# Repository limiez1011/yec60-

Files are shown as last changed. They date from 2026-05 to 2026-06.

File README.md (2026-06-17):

# yec60%

## Description
The yec60% keyboard is based on the ansi 60% layout and has 61 hotswappable sockets.

## Features
- Built in rp2040 MCU
- QMK firmware
- Hot swap sockets

## Flashing procedure
To flash firmware onto the RP2040 there are 2 pads under the "BOOT" text on the silkscreen, you must short those 2 pins to enter bootloader. Once in bootloader a drive should appear on your computer. Copy the .uf2 file from the QMK folder of the repo and paste it into the drive. Once done unplug the USB cable and plug it back in and it should be flashed.

## Credits
Credits to aio3 for his amazing tools for keyboard design, and his premade footprints. Some other people I'd love to thank is the QMK team which have created an amazing and easy to use system.

## BOM
|Name |Purpose |Quantity|Total Cost (USD)|Link |Distributor|
|---|---|---|---|---|---|
|stabilizers  |stabilizing |1 |11.00 |https://www.aliexpress.com/item/1005004229140548.html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 |aliexpress |
|keycaps |keycaps |1 |16.50 |https://www.aliexpress.com/item/1005009426980407.html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|aliexpress |
|switches |gateron milky yellow|70 |26.50 |https://www.aliexpress.com/item/1005007039372956.html?spm=a2g0o.cart.0.0.bc85452cwC4OF7&mp=1 |aliexpress |
|PCB |pcb |5 |30.00 | |JLCPCB |
|kalih sockets|hotswap |61 |3.00 |https://www.lcsc.com/product-detail/C41430893.html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 |LCSC |
|2mb flash |storage |1 |1.50 |https://www.lcsc.com/product-detail/C2986331.html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 |LCSC |
|PASSIVES |PASSIVING |1 |8.50 | |LCSC |
|DIODES |NKEY ROLLOVER |61 |4.00 |https://www.lcsc.com/product-detail/C81598.html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 |LCSC |
|XTAL |CLOCK |1 |1.00 |https://www.lcsc.com/product-detail/C9002.html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 |LCSC |
|USBC |PORT |1 |1.00 |https://www.lcsc.com/product-detail/C165948.html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 |LCSC |
|RP2040 |MCU |1 |1.00 |https://www.lcsc.com/product-detail/C2040.html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 |LCSC |
|RT9013-33GB  |LDO |1 |1.00 |https://www.lcsc.com/product-detail/C47773.html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 |LCSC |

## Photos









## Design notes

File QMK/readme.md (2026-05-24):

# yec60

yec60

*A short description of the keyboard/project*

* Keyboard Maintainer: [limiez1011](https://github.com/limiez1011)
* Hardware Supported: *The PCBs, controllers supported*
* Hardware Availability: *Links to where you can find this hardware*

Make example for this keyboard (after setting up your build environment):

    make yec60:default

Flashing example for this keyboard:

    make yec60:default:flash

See the [build environment setup](https://docs.qmk.fm/#/getting_started_build_tools) and the [make instructions](https://docs.qmk.fm/#/getting_started_make_guide) for more information. Brand new to QMK? Start with our [Complete Newbs Guide](https://docs.qmk.fm/#/newbs).

## Bootloader

Enter the bootloader in 3 ways:

* **Bootmagic reset**: Hold down the key at (0,0) in the matrix (usually the top left key or Escape) and plug in the keyboard
* **Physical reset button**: Briefly press the button on the back of the PCB - some may have pads you must short instead
* **Keycode in layout**: Press the key mapped to `QK_BOOT` if it is available

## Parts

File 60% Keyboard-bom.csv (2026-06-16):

Name | Purpose | Quantity | Total Cost (USD) | Link | Distributor
stabilizers | stabilizing | 1 | 11.00 | https://www.aliexpress.com/item/1005004229140548.html | aliexpress
keycaps | keycaps | 1 | 16.50 | https://www.aliexpress.com/item/1005009426980407.html?scm_id=1007.40050.354490.0&scm-url=1007.40050.354490.0 | aliexpress
switches | cherry mx red (62 bc one spare) | 70 | 26.50 | https://www.aliexpress.com/item/1005007039372956.html?spm=a2g0o.cart.0.0.bc85452cwC4OF7&mp=1 | aliexpress
PCB | pcb | 5 | 30.00 |  | JLCPCB
kalih sockets | hotswap | 61 | 3.00 | https://www.lcsc.com/product-detail/C41430893.html | LCSC
2mb flash | storage | 1 | 1.50 | https://www.lcsc.com/product-detail/C2986331.html | LCSC
PASSIVES | PASSIVING | 1 | 8.50 |  | LCSC
DIODES | NKEY ROLLOVER | 61 | 4.00 | https://www.lcsc.com/product-detail/C81598.html | LCSC
XTAL | CLOCK | 1 | 1.00 | https://www.lcsc.com/product-detail/C9002.html | LCSC
USBC | PORT | 1 | 1.00 | https://www.lcsc.com/product-detail/C165948.html | LCSC
RP2040 | MCU | 1 | 1.00 | https://www.lcsc.com/product-detail/C2040.html | LCSC
RT9013-33GB | LDO | 1 | 1.00 | https://www.lcsc.com/product-detail/C47773.html | LCSC

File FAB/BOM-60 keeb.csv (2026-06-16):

Comment | Designator | Footprint | LCSC | Quantity
100nF | C10,C11,C13,C14,C17,C19,C4,C5,C6,C7,C8,C9 | C_0402_1005Metric | C1525 | 12
10K | R5,R7 | R_0402_1005Metric | C25744 | 2
1K | R6 | R_0402_1005Metric | C11702 | 1
1uF | C1,C2 | C_0603_1608Metric | C15849 | 2
1uF | C12,C3 | C_0402_1005Metric | C52923 | 2
27 | R1,R2 | R_0402_1005Metric | C25156 | 2
33pF | C15,C16 | C_0402_1005Metric | C1562 | 2
5.1K | R3,R4 | R_0402_1005Metric | C25905 | 2
RP2040 | U1 | QFN-56-1EP_7x7mm_P0.4mm_EP3.2x3.2mm | C2040 | 1
RT9013-33GB | U2 | SOT-23-5_HandSoldering | C47773 | 1
USB_C_Receptacle_USB2.0_14P | J1 | USB_C_Receptacle_HRO_TYPE-C-31-M-12 | C165948 | 1
W25Q128JVSIQ | U3 | Winbond_USON-8-1EP_3x2mm_P0.5mm_EP0.2x1.6mm | C2986331 | 1
X322512MSB4SI | X1 | CRYSTAL-SMD_4P-L3.2-W2.5-BL | C9002 | 1
~ | SW10,SW11,SW12,SW13,SW14,SW15,SW16,SW17,SW18,SW19,SW2,SW20,SW21,SW22,SW23,SW24,SW25,SW26,SW27,SW28,SW29,SW3,SW30,SW31,SW32,SW33,SW34,SW35,SW36,SW37,SW38,SW39,SW4,SW40,SW41,SW42,SW43,SW44,SW45,SW46,SW47,SW48,SW49,SW5,SW50,SW51,SW52,SW53,SW54,SW55,SW56,SW57,SW58,SW59,SW6,SW60,SW61,SW62,SW7,SW8,SW9 | MXOnly-1U-Hotswap | C41430893 | 61
~ | D1,D10,D11,D12,D13,D14,D15,D16,D17,D18,D19,D2,D20,D21,D22,D23,D24,D25,D26,D27,D28,D29,D3,D31,D32,D33,D34,D35,D36,D37,D38,D39,D4,D40,D41,D42,D43,D44,D45,D46,D47,D48,D49,D5,D50,D51,D52,D53,D54,D55,D56,D6,D63,D64,D65,D66,D67,D68,D7,D8,D9 | D_SOD-123 | C81598 | 61
~ | TP2 | TestPoint_Pad_D1.0mm |  | 1
~ | TP1 | TestPoint_Pad_D1.0mm |  | 1
SW_Push | SW1 | C_0402_1005Metric_Pad0.74x0.62mm_HandSolder |  | 1

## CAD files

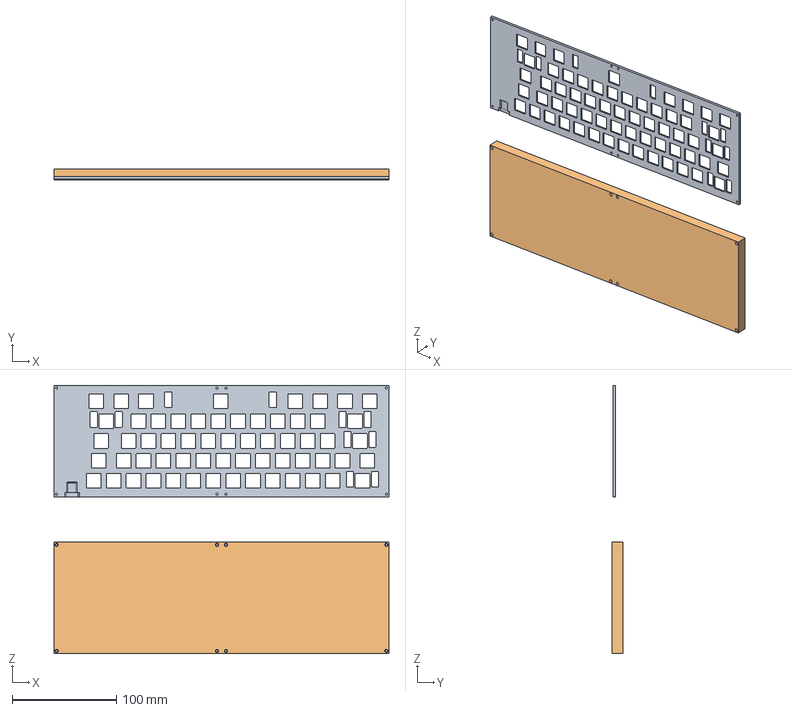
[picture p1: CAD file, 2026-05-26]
CAD/keybard.step
320.6 x 11.0 x 256.6 mm

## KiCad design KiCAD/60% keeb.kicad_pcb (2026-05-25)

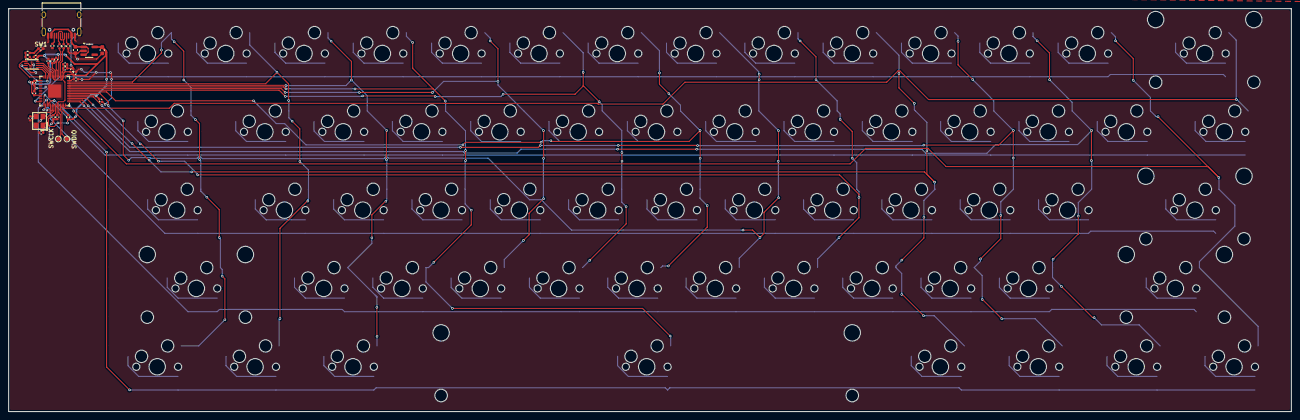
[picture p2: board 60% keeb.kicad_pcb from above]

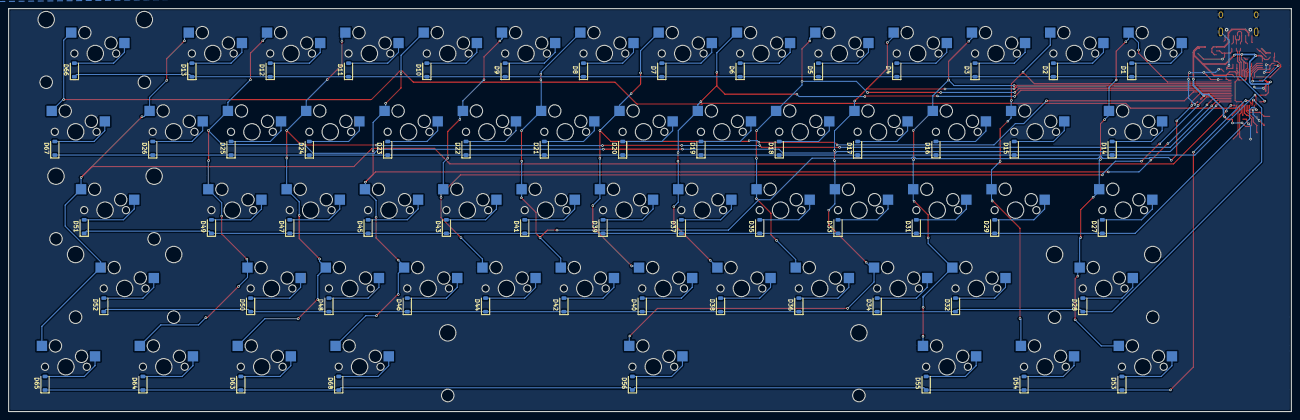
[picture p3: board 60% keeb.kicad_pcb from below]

Board: 2 copper layers, 312.0 x 98.0 mm, 155 parts (61 on the bottom side), 102 nets.

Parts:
C1, C2: 1uF; C_0603_1608Metric
C3, C12: 1uF; C_0402_1005Metric
C4, C5, C6, C7, C8, C9, C10, C11, C13, C14, C17, C19: 100nF; C_0402_1005Metric
C15, C16: 33pF; C_0402_1005Metric
D1, D2, D3, D4, D5, D6, D7, D8, D9, D10, D11, D12, D13, D14, D15, D16, D17, D18, D19, D20, D21, D22, D23, D24, D25, D26, D27, D28, D29, D31, D32, D33, D34, D35, D36, D37, D38, D39, D40, D41, D42, D43, D44, D45, D46, D47, D48, D49, D50, D51, D52, D53, D54, D55, D56, D63, D64, D65, D66, D67, D68: D_SOD-123
J1: USB_C_Receptacle_USB2.0_14P; USB_C_Receptacle_HRO_TYPE-C-31-M-12
R1, R2: 27; R_0402_1005Metric
R3, R4: 5.1K; R_0402_1005Metric
R5, R7: 10K; R_0402_1005Metric
R6: 1K; R_0402_1005Metric
SW1: SW_Push; C_0402_1005Metric_Pad0.74x0.62mm_HandSolder
SW2, SW3, SW4, SW5, SW6, SW7, SW8, SW9, SW10, SW11, SW12, SW13, SW14, SW16, SW17, SW18, SW19, SW20, SW21, SW22, SW23, SW24, SW25, SW26, SW27, SW28, SW29, SW30, SW31, SW32, SW33, SW34, SW35, SW36, SW37, SW38, SW39, SW40, SW41, SW44, SW45, SW46, SW47, SW48, SW49, SW50, SW51, SW52, SW53, SW55, SW56, SW57, SW59, SW60, SW61, SW62: MXOnly-1U-Hotswap
SW15, SW42, SW43: MXOnly-2U-Hotswap-ReversedStabilizers
SW54: MXOnly-2.75U-Hotswap-ReversedStabilizers
SW58: MXOnly-6.25U-Hotswap-ReversedStabilizers
TP1, TP2: TestPoint_Pad_D1.0mm
U1: RP2040; QFN-56-1EP_7x7mm_P0.4mm_EP3.2x3.2mm
U2: RT9013-33GB; SOT-23-5_HandSoldering
U3: W25Q128JVSIQ; Winbond_USON-8-1EP_3x2mm_P0.5mm_EP0.2x1.6mm
X1: X322512MSB4SI; CRYSTAL-SMD_4P-L3.2-W2.5-BL

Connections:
+1V1: C12.2, C13.2, C14.2, C19.2, U1.23 (DVDD), U1.45 (VREG_VOUT), U1.50 (DVDD)
+3.3V: C2.1, C3.2, C4.2, C5.2, C6.2, C7.2, C8.2, C9.2, C10.2, C11.2, C17.1, R5.1, R7.1, U1.1 (IOVDD), U1.10 (IOVDD), U1.22 (IOVDD), U1.33 (IOVDD), U1.42 (IOVDD), U1.43 (ADC_AVDD), U1.44 (VREG_VIN), U1.48 (USB_VDD), U1.49 (IOVDD), U2.5 (VOUT), U3.8 (VCC)
/CS: R5.2, R6.1, U1.56 (~QSPI_SS), U3.1 (/CS)
/D+: J1.A6 (D+), J1.B6 (D+), R2.1
/D-: J1.A7 (D-), J1.B7 (D-), R1.1
/DN: R1.2, U1.46 (USB_DM)
/DP: R2.2, U1.47 (USB_DP)
/SCLK: U1.52 (QSPI_SCLK), U3.6 (CLK)
/SD0: U1.53 (QSPI_SD0), U3.5 (DI(IO0))
/SD1: U1.55 (QSPI_SD1), U3.2 (DO(IO1))
/SD2: U1.54 (QSPI_SD2), U3.3 (/WP(IO2))
/SD3: U1.51 (QSPI_SD3), U3.7 (/HOLD/RESET(IO3))
/XIN: C15.2, U1.20 (XIN), X1.3 (OSC2)
/XOUT: C16.1, U1.21 (XOUT), X1.1 (OSC1)
COL0: SW2.2, SW16.2, SW30.2, SW43.2, SW55.2, U1.41 (GPIO29/ADC3)
COL1: SW3.2, SW17.2, SW31.2, SW56.2, U1.40 (GPIO28/ADC2)
COL2: SW4.2, SW18.2, SW32.2, SW44.2, SW57.2, U1.39 (GPIO27/ADC1)
COL3: SW5.2, SW19.2, SW33.2, SW45.2, SW58.2, U1.38 (GPIO26/ADC0)
COL4: SW6.2, SW20.2, SW34.2, SW46.2, U1.37 (GPIO25)
COL5: SW7.2, SW21.2, SW35.2, SW47.2, U1.36 (GPIO24)
COL6: SW8.2, SW22.2, SW36.2, SW48.2, U1.35 (GPIO23)
COL7: SW9.2, SW23.2, SW37.2, SW49.2, U1.34 (GPIO22)
COL8: SW10.2, SW24.2, SW38.2, SW50.2, U1.32 (GPIO21)
COL9: SW11.2, SW25.2, SW39.2, SW51.2, SW59.2, U1.31 (GPIO20)
COL10: SW12.2, SW26.2, SW40.2, SW52.2, SW60.2, U1.30 (GPIO19)
COL11: SW13.2, SW27.2, SW41.2, SW53.2, SW61.2, U1.29 (GPIO18)
COL12: SW14.2, SW28.2, SW42.2, SW54.2, SW62.2, U1.28 (GPIO17)
COL13: SW15.2, SW29.2, U1.27 (GPIO16)
GND: C1.1, C2.2, C3.1, C4.1, C5.1, C6.1, C7.1, C8.1, C9.1, C10.1, C11.1, C12.1, C13.1, C14.1, C15.1, C16.2, C17.2, C19.1, J1.A1 (GND), J1.A12 (GND), J1.B1 (GND), J1.B12 (GND), J1.SH (SHIELD), R3.2, R4.2, SW1.2, U1.19 (TESTEN), U1.57 (GND), U2.2 (GND), U3.4 (GND), U3.9, X1.2 (GND), X1.4 (GND)
unnamed: D1.2 (A), SW2.1
unnamed: D2.2 (A), SW3.1
unnamed: D3.2 (A), SW4.1
unnamed: D4.2 (A), SW5.1
unnamed: D5.2 (A), SW6.1
unnamed: D6.2 (A), SW7.1
unnamed: D7.2 (A), SW8.1
unnamed: D8.2 (A), SW9.1
unnamed: D9.2 (A), SW10.1
unnamed: D10.2 (A), SW11.1
unnamed: D11.2 (A), SW12.1
unnamed: D12.2 (A), SW13.1
unnamed: D13.2 (A), SW14.1
unnamed: D14.2 (A), SW16.1
unnamed: D15.2 (A), SW17.1
unnamed: D16.2 (A), SW18.1
unnamed: D17.2 (A), SW19.1
unnamed: D18.2 (A), SW20.1
unnamed: D19.2 (A), SW21.1
unnamed: D20.2 (A), SW22.1
unnamed: D21.2 (A), SW23.1
unnamed: D22.2 (A), SW24.1
unnamed: D23.2 (A), SW25.1
unnamed: D24.2 (A), SW26.1
unnamed: D25.2 (A), SW27.1
unnamed: D26.2 (A), SW28.1
unnamed: D27.2 (A), SW30.1
unnamed: D28.2 (A), SW43.1
unnamed: D29.2 (A), SW31.1
unnamed: D31.2 (A), SW32.1
unnamed: D32.2 (A), SW44.1
unnamed: D33.2 (A), SW33.1
unnamed: D34.2 (A), SW45.1
unnamed: D35.2 (A), SW34.1
unnamed: D36.2 (A), SW46.1
unnamed: D37.2 (A), SW35.1
unnamed: D38.2 (A), SW47.1
unnamed: D39.2 (A), SW36.1
unnamed: D40.2 (A), SW48.1
unnamed: D41.2 (A), SW37.1
unnamed: D42.2 (A), SW49.1
unnamed: D43.2 (A), SW38.1
unnamed: D44.2 (A), SW50.1
unnamed: D45.2 (A), SW39.1
unnamed: D46.2 (A), SW51.1
unnamed: D47.2 (A), SW40.1
unnamed: D48.2 (A), SW52.1
unnamed: D49.2 (A), SW41.1
unnamed: D50.2 (A), SW53.1
unnamed: D51.2 (A), SW42.1
unnamed: D52.2 (A), SW54.1
unnamed: D53.2 (A), SW55.1
unnamed: D54.2 (A), SW56.1
unnamed: D55.2 (A), SW57.1
unnamed: D56.2 (A), SW58.1
unnamed: D63.2 (A), SW60.1
unnamed: D64.2 (A), SW61.1
unnamed: D65.2 (A), SW62.1
unnamed: D66.2 (A), SW15.1
unnamed: D67.2 (A), SW29.1
unnamed: D68.2 (A), SW59.1
unnamed: J1.A5 (CC1), R3.1
unnamed: J1.B5 (CC2), R4.1
unnamed: R6.2, SW1.1
unnamed: R7.2, U1.26 (RUN)
unnamed: TP1.1 (1_1), U1.24 (SWCLK)
unnamed: TP2.1 (1_1), U1.25 (SWDIO)
ROW0: D1.1 (K), D2.1 (K), D3.1 (K), D4.1 (K), D5.1 (K), D6.1 (K), D7.1 (K), D8.1 (K), D9.1 (K), D10.1 (K), D11.1 (K), D12.1 (K), D13.1 (K), D66.1 (K), U1.14 (GPIO11)
ROW1: D14.1 (K), D15.1 (K), D16.1 (K), D17.1 (K), D18.1 (K), D19.1 (K), D20.1 (K), D21.1 (K), D22.1 (K), D23.1 (K), D24.1 (K), D25.1 (K), D26.1 (K), D67.1 (K), U1.15 (GPIO12)
ROW2: D27.1 (K), D29.1 (K), D31.1 (K), D33.1 (K), D35.1 (K), D37.1 (K), D39.1 (K), D41.1 (K), D43.1 (K), D45.1 (K), D47.1 (K), D49.1 (K), D51.1 (K), U1.16 (GPIO13)
ROW3: D28.1 (K), D32.1 (K), D34.1 (K), D36.1 (K), D38.1 (K), D40.1 (K), D42.1 (K), D44.1 (K), D46.1 (K), D48.1 (K), D50.1 (K), D52.1 (K), U1.17 (GPIO14)
ROW4: D53.1 (K), D54.1 (K), D55.1 (K), D56.1 (K), D63.1 (K), D64.1 (K), D65.1 (K), D68.1 (K), U1.18 (GPIO15)
VBUS: C1.2, J1.A4 (VBUS), J1.A9 (VBUS), J1.B4 (VBUS), J1.B9 (VBUS), U2.1 (VIN), U2.3 (EN)

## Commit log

2026-06-16 Update BOM with new components and details
    Added new components to the BOM including stabilizers and keycaps with links and costs.
2026-06-16 Update switches from cherry mx red to gateron milky yellow
